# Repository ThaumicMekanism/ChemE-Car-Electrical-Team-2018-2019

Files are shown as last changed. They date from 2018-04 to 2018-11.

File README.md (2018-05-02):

# ChemE-Car-Electrical-Team-2018-2019
These are the programs and files used to create the electrical box for the ChemE Car club for 2018-2019.

More info about the program used can be found in the motor controller file.

Info about circuit design can be found in the fritzing files and pictures.

For a base rundown about how to use the box, please read the electrical_box_details file

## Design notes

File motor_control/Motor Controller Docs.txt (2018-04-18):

/////////////////////////////////////////////////////////
///////////////ChemE Car Motor Controller////////////////
/////////////////////////////////////////////////////////
//Created by Stephan K for the ChemE Car Team 2017-2018//
/////////////////////////////////////////////////////////

=======
|Index|
=======
1. Overview
    a. Features
        i.      Currently Implemented Control Inputs
        ii.     Smart Control
        iii.    Blink Led
        iv.     Voltage Controller
        v.      Logger
    b. Usage (modes)
    	i.		General Information
    	ii.		Normal Mode
    	iii.	Smart Control Mode
    	iv.		Always Run Mode
    	v.		Logger Mode
    	vi. 	Voltage Controller Mode
2. Functions (Litterally what the functions in the program do. This goes in more detail than the features.)
3. Settings
4. Updates
5. License

=============
|1) Overview|
=============

This program is meant to run on an arduino uno or some board with the same pinout/interface. The purpose of this program is to detect some chemical timer to allow a motor to run when the chemical timer tells it to. It controlls the power to the motor through a transistor. The transistor connects the positive from the batter to the motor positive and will only supply power when the board sends a high signal to the board. 

+++++++++++++++
|1.a) Features|
+++++++++++++++

---------------------------------------------
|1.a.i) Currently Implemented Control Inputs|
---------------------------------------------

Currently there are a total of 2 control inputs. One is digital and the other is analog. 

1. Digital Input: 
The digital control input is just as it sounds, it will accepts an on or off signal from the control team and will be processed as need depending on what we set on and off to be. The accepted voltage range for the digital input on the arduino is 0V-5V. Voltages higher or lower than this CAN damage the board. In our current place, we are using a digital light sensor which emmits on if the motor should be on and off if the motor should be off. Other digital devices which function similarly will also work just as well.

2. Analog Input: 
The analog input will accept any voltage between 0V and 5V. Any voltage out of this range CAN damage the board. The analog input is different than the digital input because it reades the voltage in comparison to the reference voltage. This produces a range of 1024 values from 0 to 1023. The current state of the program just has it so if the number read by the analog in is greater than 0, then the motor should be on. If it is equal to 0, the motor should be off. This is not optimal because noise can give false positives which could be problematic. Our current setup which uses this system uses a light sensor which is connected through a voltage divider to the analog pin to read the value of the light sensor.

-----------------------
|1.a.ii) Smart Control|
-----------------------

This is a feature I created if we had a reaction which we just wanted to time to get to a specific state and would return to its initial state after a little bit of time. This feature waits for a 'reset' button to be pressed to initially turn on the motor. It then samples the control input's value over every iteration, if the state is what we want, it increments a counter. After a set amount of time which we set, it will compare the number of loops vs the number of times the control input was not at the state which we want (which designates if the motor should turn on). If this number is greater than the threshold (currently set to half the total number of checks in that interval), it will set the motor state to off and will NOT turn the motor on until the reset button is pressed again REGARDLESS of the buttons' state. This is a great feature if you know that the stop condition which you want will last for a little bit of time but not long enough for your needs.

--------------------
|1.a.iii) Blink Led|
--------------------

This feature allows for us to set the output of some pins to on and off for some time. In short, it allows us to cause an LED to blink WITHOUT having the program halt to blink it. It uses a timer and has the ability to control the number of blinks it makes (or can go until a function stops it). You can adjust the length of time the LED is on and off for as well.

-------------------------
|1.a.iv) Voltage Control|
-------------------------

This feature is currently in development. It is not FULLY implemented yet. Eventually it will read in the voltage and amperage that the battery is giving to the motor and then set the PWM to the transistor to decrease the voltage given to the motor effectively controlling the speed of the motor. More will be said about this once it is implemented.

---------------
|1.a.v) Logger|
---------------

This utilizes the same components as the Voltage Controller plus an SD card read/writer. It will read the voltage and amperage from the battery and print that data to a file on the sd card. I would also like for it to display distance but who know how that will go.

++++++++++++
|1.b) Usage|
++++++++++++

----------------------------
|1.b.i) General Information|
----------------------------

To turn on the box, you will press the button which connects the 9v battery to the arduino. If you want the power from the battery to flow to the motor, you need to make sure you have the motor button pressed. If this is not pressed, the motor WILL NOT RUN regardless of if the arduino tells it to. The next button currently is set to telling the board if it should read the digital or analog control input. A change to the buttons state will instantly be reflected by the control system. The last button is dubbed the 'Smart Control Button' this button enables 'Normal Mode', 'Smart Control Mode', 'Always Run Mode', and the 'Logger Mode'. More about how you can switch between the different modes can be found below.

---------------------
|1.b.ii) Normal Mode|
---------------------

How to enable:
To enable this mode, you need to make sure that the Smart Control Switch is turned OFF when the board starts up. This is ONLY checked on the startup loop. If you want to switch to the 'Smart Control Mode', you will have to turn off the arduino and then start it up with the correct buttons pressed. 

What this mode does:
The motor will turn on and off based off of the state of the control input DIRECTLY.

You will know that this mode is activated on start because the board on LED will stay steadly on unlike the smart control mode.

-----------------------------
|1.b.iii) Smart Control Mode|
-----------------------------

How to enable:
To enable this mode, you need to make sure the Smart Control Switch is turned ON when the board starts up. This is ONLY checked on the startup of the loop. I you want to switch back to 'Normal Mode', you will have to turn off the arduino and then with the correct buttons pressed.

What this mode does:
This mode runs the smart control function to control the motor instead of directly controlling the motor. More can be found about this in the [Features -> Smart Control] section of the documentation.

You will know that this mode is activated on start because the board on LED will blink for a few seconds on boot.

-------------------------
|1.b.iv) Always Run Mode|
-------------------------

How to enable:
First, enter into 'Normal Mode' (see how to do this above). After you have entered 'Normal Mode', turn the Smart Control Switch to ON. To return to the 'Normal Control Mode', just turn the Smart Control Switch to OFF.

============
|5) License|
============

Currently this project is under the Apache License v2.0. More info can be found in the LICENSE.md file in the root of this repository.

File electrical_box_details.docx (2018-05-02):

Kaminsky, Stephan

ChemE Car Team

4/26/18

The Electrical Box

The electrical box is an important part of the car. It is the device which controls whether power should go from the battery to the motor. That connection is determined by an Arduino which reads an input from a chemical reaction, which is the timer, and then allows power to flow to the motor depending on the state of the chemical timer. The box also has two LED’s on the front of it. The blue LED with an ‘i’ below it signifies that the board is ‘ready’ and is in its looping state. The green LED with a motor icon below it will turn on if the motor should be going. This is helpful in debugging if a connection is not properly hooked up or if the box is not set up fully.

The box is designed to be easy to setup and use. There are four female banana plugs on one side of the box. They come in two pairs, one red and one black for each pair. The pair which has a motor icon below it is meant to be hooked up to the motor and the one with the battery icon below it should be connected to the power source. In both cases, the positive (red banana plug) of the battery/motor should be connected to the positive on the box while the negative (black banana plug) of the battery/motor should be hooked up to the negative of the box. Since the motor is bidirectional, it does not matter how this is hooked up. The direction of the motor is the only thing which changes if it is hooked up the other way. This does not matter too much but we want the motor to go in the right direction on the first attempt. The battery connection on the box is NOT bidirectional and will not work if it is hooked up the wrong way. This is because the box uses a transistor to allow power from the battery to flow to the motor. If the battery is hooked up the wrong way, then even if a high signal was sent to the transistor (telling it to be on), it will never be able to turn on. This is due to how the transistor is made: it will not allow the flow of electrons unless the gate is above a certain threshold in relation to the source and drain. Since they would be flipped, that threshold will never cross and it will not run. There is also a chance that it would damage the Arduino as well.

The box also has different functions which are activated by the different button switches on the side of it. The first red switch with an Arduino logo below it allows for a 9V battery to be connected to the Arduino to power it. The other red switch with a motor symbol below closes the circuit of the battery. If this switch is off, no matter what state the motor should be due to the Arduino, no voltage will flow from the battery since there is not a closed circuit from the battery to the motor. This is useful so that we do not drain the battery faster than we want to. There are also two green buttons on the box. One of them controls whether the Arduino is checking the digital or analog input connection. If the switch is off, it check the digital connection, if it is on, it checks the analog connection for if the motor should be running or not. The other switch is called the Smart control switch and controls the different functions the box has.

There are a total of four different modes which the box has: Normal mode, Smart Control Mode, Always On Mode, and Logger Mode. Normal mode is activated by leaving the smart control switch (SCS) in the off state when the board boots up and then stays in the off state while the board is running. In this mode, the motor’s state will match the input control’s state. The Always on mode is activated by first going into Normal mode and then turning on the SCS. In this mode, the motor will always be on regardless of the input control’s state. This is useful for when a power team wants to test but does not want to worry about making sure the input control is in the on state.

The third mode is the Smart Control mode. This state is activated by having the SCS in the on state when the Arduino boots up and then have the SCS stay in the on state when the board is running. This state also uses the button which is on the front of the box. In this state, the motor will not turn on until the button in front is pressed. Once that button is pressed, the motor will stay on until the input control is in the off state for a short period of time. Once input control is in the off state for a majority of the current checking period, the motor will not turn back on even if the input control says it should turn back on. It is then reset when the button in front is pressed. This is helpful for reactions which stay in the on state for a period of time and then turn off when we want it to turn off but then go back to the on state after a little bit of time (bell shaped reactions where we want to stop at the peak). It is meant to be a safety measure for unstable reactions. The fourth mode is the Logger mode and has not been fully implemented yet. It is activated by going into the Smart Control Mode and then having the SCS in the off state when the board is running. This mode will allow for the Arduino to take data of the battery and distance but this has not been fully implemented yet.

The control input is from a digital or analog input. The analog input uses an ambient light sensor hooked up with a voltage divider to the Arduino. The Arduino then reads the value which will be from 0V to 5V. Currently if it detects anything above 0V, the control input signal is considered to be on. This is not perfect due to the noise which is inherent in electronic systems. This is currently implemented in the box but is not being currently used. The other control input which is being primarily used is the digital light sensor. A digital light sensor will send a digital signal to the Arduino of whether the motor should be on or off based off of the reaction. The Arduino will then process the input of the control input which is selected from the analog/digital button.

These are the different features of the current box. In the future, we plan to create a printed circuit board with Arduino Nano instead of a protoshield with an Arduino uno. This will help decrease the footprint of the electrical system and hopefully allow us to add more cool features.

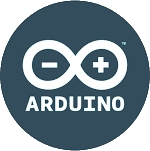
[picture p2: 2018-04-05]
Box/Images/arduino.jpg

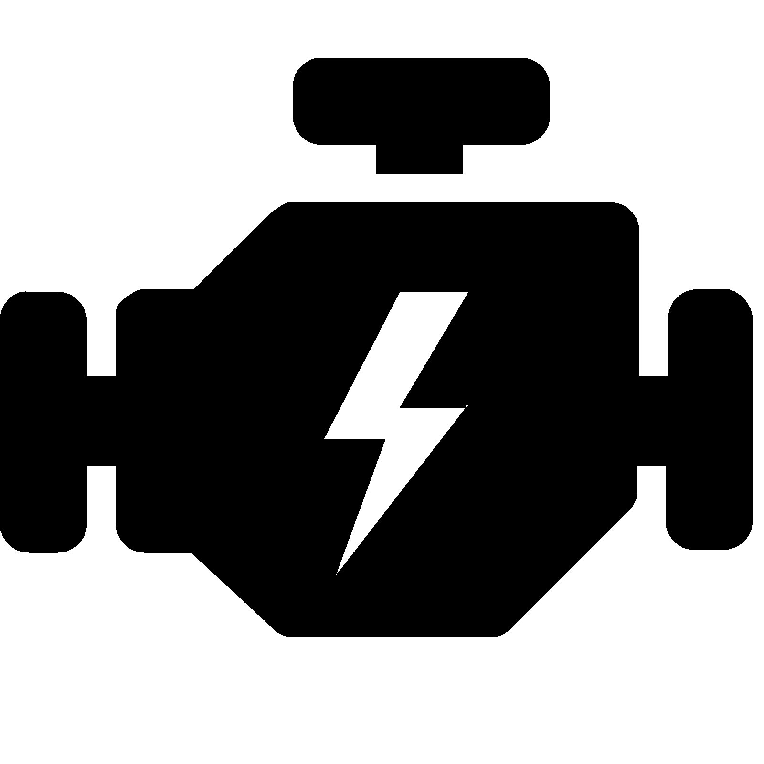
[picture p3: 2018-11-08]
Box/Images/engine.jpg

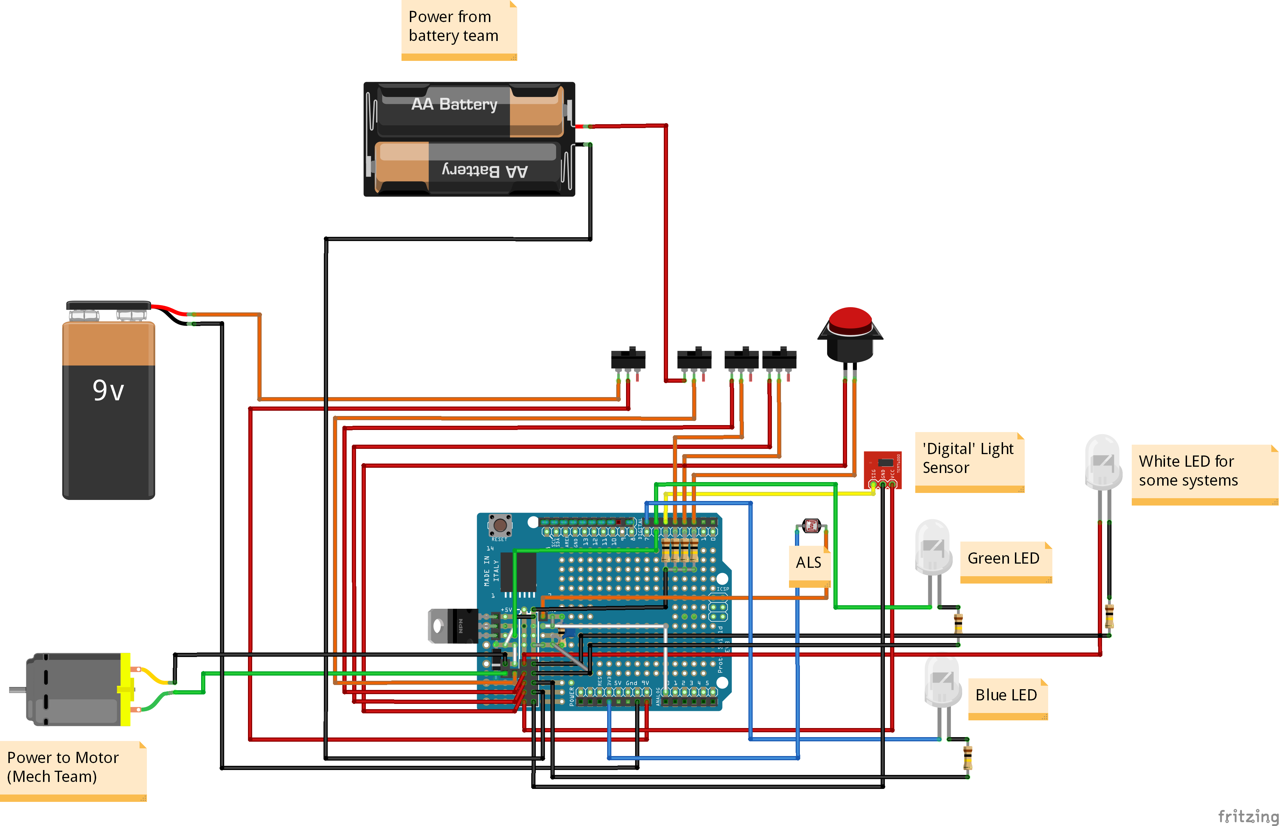
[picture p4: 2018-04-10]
Circut Diagram ChemE Car EE Team 2017-2018_bb.png

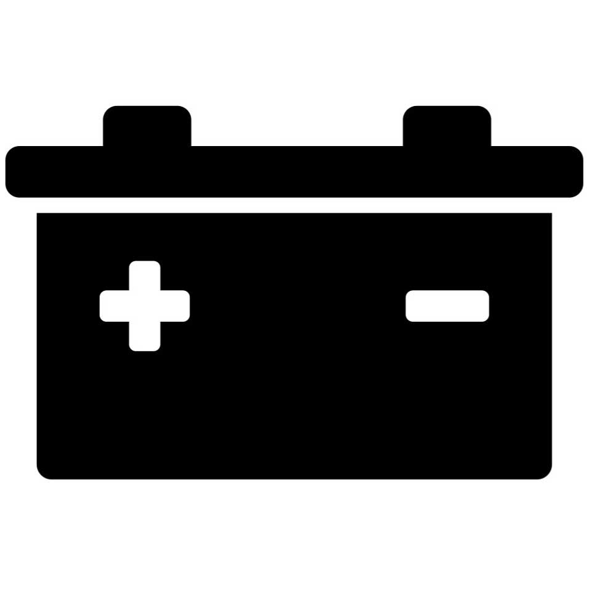
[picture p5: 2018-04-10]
Box/Images/battery.jpg

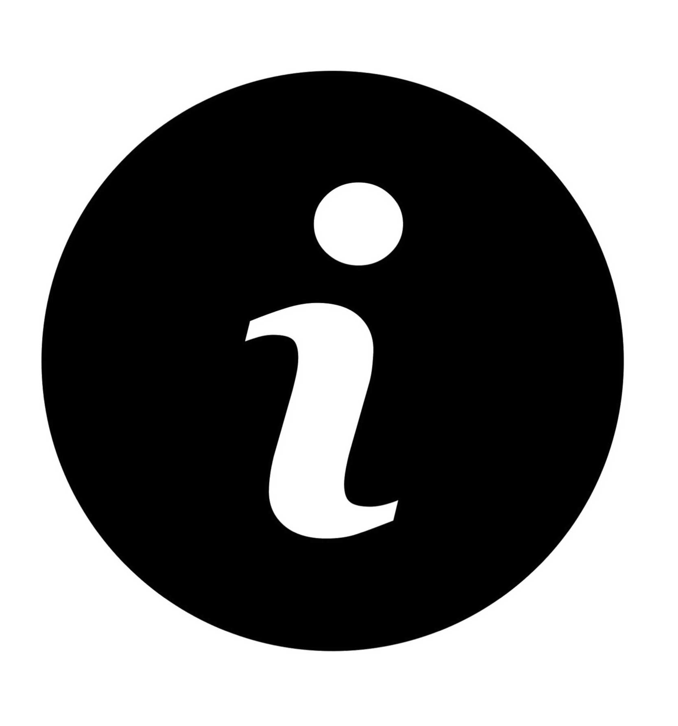
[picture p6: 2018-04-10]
Box/Images/info.jpg

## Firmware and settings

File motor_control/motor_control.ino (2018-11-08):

/////////////////////////////////////////////////////////
//Created by Stephan K for the ChemE Car Team 2018-2019//
/////////////////////////////////////////////////////////
/*/////// \\\\\\\\\ 
|||||Includes||||||
\\\\\\\\\ ///////*/
#include <EEPROM.h> //This includes the functions which eeprom uses so that we can store data even when the board looses power.
#include "BlinkLed.h"
#include "Logger.h"

/*/////// \\\\\\\\\ 
|||||Variables|||||
\\\\\\\\\ ///////*/
/* Variables used in the program. */
#include "pins.h"
#include "settings.h"
#include "debug.h"

//Other Variables\\
/* These are variables which should not be changed. These are required for the program to run. */

int loops = 0;
int checked_loops = 0;
int state = 0;
unsigned long previousMillis = 0;
unsigned long currentTime = 0;
bool smart_control = true;
bool allow_button = true;
bool smart_switch = false;
bool smart_switch_prev = false;
unsigned long button_timeout = 0;
bool resetState = false;
BlinkLed* blinkled;
Logger* logger;

//END Other Variables

/*///////// \\\\\\\\\\\
|||||END Variables|||||
\\\\\\\\\\\ /////////*/

void setup() {
  //PinMode Setup\\

  pinMode(digitalSensor, INPUT);
  pinMode(analogSensor, INPUT);
  pinMode(motor, OUTPUT);
  pinMode(resetb, INPUT);
  pinMode(board_ready, OUTPUT);
  pinMode(smart_control_switch, INPUT);
  //pinMode(decrease_buffer_switch, INPUT);
  pinMode(adLightSwitch, INPUT);


  //END PinMode Setup\\

  //Turns the motor on if the variable on is true.
//  if(on == true){
//    motorOn();
//  }

  

  //Switches to change settings
  if(allow_switches == true){
    smart_control = digitalRead(smart_control_switch);
  }
  
  //Debug Channel Init (Initiates regardless of if it is called or not later.)
  Serial.begin(channel);

  blinkled = new BlinkLed();
  logger = new Logger(&on, &smart_switch, &resetState, &state);
  VCinit();

  //Lights led since the board should be ready and is now looping.
  if(debug_board_ready){
    digitalWrite(board_ready, HIGH);
  }

  //Writes to the console the results of the previous time it was measuring.
  //writeTimer();
  parserinit();
  
  //Causes the ready light to flicker if smart control is on.
  if(smart_control) {
    blinkled->add(board_ready, 100, 10, 0);
  } else {
    //timerInit();
  }
  
}

void loop() {
  //unsigned int time = 0;
  //time = micros();
  parser();
  
  //Gets the current milliseconds time.
  currentTime = millis();

  //Some classes 'tick' where they update values with all fns running instead of having their own for loops and halting the code.
  blinkled->tick(currentTime);
  logger->tick(currentTime);
  VCCheckVoltage();
  
  //Gets the state of the sensor pin (HIGH(1)/LOW(0))
  state = lightSensor(digitalRead(adLightSwitch)); 
  //state = lightSensor(whichSensor); 
  
  smart_switch_prev = smart_switch;
  smart_switch = digitalRead(smart_control_switch);
  
  resetState = readBtn(resetb, resetState);

  //DEBUG\\
  
  if(debug_state){
    Serial.print("Sensor state: ");
    Serial.println(state);
  }
  if(debug_on){
    Serial.print("Motor: ");
    Serial.println(on);
  }
  
  //END DEBUG\\
  
  if(smart_control){
    smartfn();
  }else {
    if (smart_switch_prev != smart_switch) {
      if (smart_switch) {
        blinkled->add(board_ready, 250, -1, 0);
      } else {
        blinkled->rem(board_ready, HIGH);
      }
    }
    if (smart_switch) {
        state = true;
    }
    if(state == check){
      on = true;
    }else{
      on = false;
    }
    //motorOn();
  }
  //If the variable on is false, turn the motor off. (!false = true)
  //motorOff();
  setMotor();
  //time = micros() - time;
  //Serial.println(time, DEC);
}

bool readBtn(int pin, bool prev) {
  if (currentTime - button_timeout > 100) {
    button_timeout = currentTime;
    bool st = digitalRead(pin);
    return st;
  } else {
    return prev;
  }
}

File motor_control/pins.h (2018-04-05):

#ifndef pins_h
#define pins_h
/*These are the pins which the arduino uses. */

#define digitalSensor 5 //Sensor Digital Pin (INPUT)
#define analogSensor A0 //Sensor Analog Pin (INPUT)
#define motor 6 //Motor Digital Pin (OUTPUT)
#define resetb 2 //Reset Digital Pin (INPUT)
#define board_ready 7 //Activates when the board is ready. (OUTPUT) (Meant for a LED)
//int check_state_switch = 9; //Determins whether to check for high or low state On/Off. (INPUT) (ONLY CHECKED WHEN: board first starts up)
//#define decrease_buffer_switch 9 //Switch TBD (INPUT) (ONLY CHECKED WHEN: board first starts up)
#define adLightSwitch 3 //Changes which light sensor is read (aka. digital (on) or analog (off)) (INPUT)
#define smart_control_switch 4 //Gets switch input to use or don't use the smart control On/Off. (INPUT) (ONLY CHECKED WHEN: board first starts up)
//NOTE for smart_control_switch: This is only checked when the board is turned on!!!
//This allows the optimized checking if the motor should be on or off. 
//This makes the reset and other checking if false not work. 
//The motor will be ON or OFF based off of the state of the sensor which we are checking for.
#define chipselect 10


#endif

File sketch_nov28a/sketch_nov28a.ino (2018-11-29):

#include <SD.h>
#include <SPI.h>

void setup() {
  // put your setup code here, to run once:
  SD.begin(10);
  Serial.begin(115200);
  String fn = "tesasdff.txt";
  File f = SD.open(fn, FILE_WRITE);
  Serial.println(f);
  f.close();
  Serial.println(SD.exists(fn));
}

void loop() {
  // put your main code here, to run repeatedly:

}

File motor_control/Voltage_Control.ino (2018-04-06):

/**
 * This file will be in control of detecting current voltage and altering motor speed based off of this.
 * 
 * NOTE: Set controlledVoltage to true if setting motors PWM from here so that it does not get reset during the motor state part of the function.
 */


unsigned int VCpwmVal = 255;
Adafruit_INA219 VCina219;


// Let's compare an average of 100
const byte averageCount = 100;
// Variables for the Modified Moving Average
float movingAverage;
float movingAverageSum;
#define analogPin 

void VCinit() {
  #warning "Need to set analogRead to the correct reading."
  return;
  VCina219.begin();
  // Pre-load MMA
  
//  for (int x=0; x < averageCount; x++)
//    
//    //movingAverageSum = movingAverageSum + analogRead(analogPin);
//     
//   // Calculate inital average
//   movingAverage = movingAverageSum / averageCount;
}


void setMotor() {
    if(on){
        if (useVoltageControl) {
            VCsetMotorPWM();
        } else {
            digitalWrite(motor, HIGH);
        }
    } else {
        digitalWrite(motor, LOW);
      }
}

void VCsetMotorPWM() {
  if (useVoltageControl) {
    analogWrite(motor, VCpwmVal);
  }
}

void VCCheckVoltage() {
    #warning "Need to implement Voltage check"
  return;
  unsigned int currentValue = VCina219.getBusVoltage_V();
  // Remove previous movingAverage from the sum
  movingAverageSum = movingAverageSum - movingAverage;
  // Replace it with the current sample
  movingAverageSum = movingAverageSum + currentValue;
  // Recalculate movingAverage
  movingAverage = movingAverageSum / averageCount;
  /*
  if (movingAverage < volatgeminustolerance) {
    
  } else if (movingAverage > voltageplustolerance) {
    
  }
  */
}

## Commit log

2017-04-17 Added the motor controler files for arduino from last year.
2017-09-28 Working on building the circut diagram
    [Circut Diagram ChemE Car EE Team 2017-2018.fzz]
2017-09-29 Updated schematic to the mostly complete version.
    [Circut Diagram ChemE Car EE Team 2017-2018.fzz]
2017-09-29 Cleaned up the wires
    [Circut Diagram ChemE Car EE Team 2017-2018.fzz]
2017-09-29 Cleaned up some more wires
    [Circut Diagram ChemE Car EE Team 2017-2018.fzz]
2017-09-29 Moved the negative of the motor to the correct spot
    [Circut Diagram ChemE Car EE Team 2017-2018.fzz]
2017-09-29 Modified the motor so the circut should be correct
    [Circut Diagram ChemE Car EE Team 2017-2018.fzz]
2017-09-29 Named a few wires, fixed different stuff too
    [Circut Diagram ChemE Car EE Team 2017-2018.fzz]
2017-09-29 Added extra led which will be used by certain timers
    [Circut Diagram ChemE Car EE Team 2017-2018.fzz]
2017-09-30 Moved on light and motor power
    [Circut Diagram ChemE Car EE Team 2017-2018.fzz]
2017-10-04 Added jumper to digital light sensor for battery teams.
    [Circut Diagram ChemE Car EE Team 2017-2018.fzz]
2017-10-04 Added missing part
    [ambient light sensor.fzz]
2017-10-04 Updated changes.
    [Circut Diagram ChemE Car EE Team 2017-2018.fzz]
2017-10-05 Removed code preventing flickering button issue. This was a software fix for an issue with hardware. This was fixed in the new circut design.
    [Smart_Control.ino, motor_control.ino]
2017-10-05 Removed the button buffer. Added a new file which will be keeping track of timing data.
2017-10-06 Added delay for button reading of 100ms just incase there is a flicker. Also finished the timing stuff.
2017-10-06 Added basic switching between light sensors. This is currently only changable in the code but in the future will be probably due to a switch on startup.
2017-10-10 Added a class to measure voltage using a voltage divider.
2017-10-16 Removed voltmeter code. Kept in the class for later testing.
2017-10-25 Fixed years in the motor_control file
    [motor_control.ino]
2017-11-02 upated the laser cut plans for the box
2017-11-30 Updated laser cutter plans
2017-12-01 Minor text fixes. Also added some timing tests into code.
    [Logger.h, Timer.ino, motor_control.ino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]
2017-12-01 Added example file for what pointers change what to. Am working on fixing the logger class to work
    [Logger.h, examplePointers.ino]
2017-12-01 Updated logger so it should function correctly. Have not tested it. Depricated the timer.ino file in lue of new logger class. Updated the pins.h and settins.h to have compiler check to not reinclude 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
    [Logger.h, Timer.ino, motor_control.ino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]
2017-12-01 Added voltage_control which will read and adjust the pwm to try to keep a constant voltage in hopes of keeping a constant speed for the car. THIS IS A WORK IN PROGRESSgit statusgit status
2017-12-01 Removed the old not used motor speed control. This will not be needed since the new control if set to active will be based off of voltage.
2017-12-01 Useful info on moving average with the voltage and PWM.
2017-12-01 More Voltage control setup
2018-01-25 Updating branch
    [Circut Diagram ChemE Car EE Team 2017-2018.fzz]
2018-02-06 Added some motor demo's and test
2018-02-08 Updates to program. Still working on the motor controller
2018-04-04 Fixed program a little more. Also added another img
    [motor_control.ino, settings.h]
2018-04-06 Updated light sensor to reflect digital stuff
2018-04-06 Fixed parts of the program to make them function properly
    [Logger.h, Smart_Control.ino, Voltage_Control.ino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]
2018-04-10 Fixed printing issues
    RIP US
2018-04-11 Removed the logger tick so that it does not run should just not cause issues.
    [motor_control.ino]
2018-04-18 Added motor controller documentation
2018-04-18 Added information for blink led
2018-05-02 Added eagle files for the pcb board
